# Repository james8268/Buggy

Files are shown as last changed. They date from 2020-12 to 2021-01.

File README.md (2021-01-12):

# Read Me file for understanding how to use the Buggy.

## Functionality of the Buggy. 
The Buggy has 3 main forms of interaction; a remote mode where the buggy can be controlled by the user through Bluetooth/WiFi/IR commands, an autonomous mode where the buggy is commanded by the user to roam freely without colliding into obstacles and a measuring mode where the buggy will move around autonomously but will take temperature and water level reading when it stops due to an obstacle. 

There are 4 methods of controlling the buggy:
* IR Remote
* Bluetooth LE
* WiFi
* Direclty through the PC serial monitor. 

## Getting started. 
When using any method of control, when then buggy is powered up it will request the user to present the correct RFID tag/card to the scanner. If the user does not present the correct RFID tag/card then access to the buggy will be denied. In order to be able to use the buggy the RFID tag/card must be presented. 





Once access is granted the user can then control the buggy by any of the control methods. 

## How to use the IR Remote. 
The IR remote is the most simple way of interacting with the buggy. This method does not use the ESP32 so this can be disconnected via the RX and TX pins.



The function each button has is as follows:  
* 1 - Move the buggy farwards slowly.
* 2 - Move the buggy forwards 
* 3 or up arrow - Move the buggy forwards at maximum speed. 
* down arrow - Reverse the buggy
* ok - Stop the buggy
* Left arrow - Rotates the buggy left
* Right arrow - rotates the buggy right
* \* - take a temperature reading and display it on the LCD screen
* \# - Stops the buggy before taking a water level reading. 

## How to control the buggy using Bluetooth low energy (BLE).
When the Bluetooth.ino code has been uploaded to the ESP32 you can connect an android device only (IOS does not support BLE).
By going into the android device settings, "ESP32test" will be able to be paired with the device. 



Then using the below Serial Bluetooth terminal, the ESP32 can be set up as a device and connected to the ESP32.




As you can see in the bluetooth terminal there are hot keys provided. Like the IR remote the number "3" will move the buggy at full speed and the hotkey "stop" will stop the buggy. 



To allow the buggy to roam autonomously and roam autonomously while taking temperature, humidity and water level measurements, "E" and "M" can be sent to the terminal respectively. To stop the buggy roaming autonomously just press the "stop" hotkey.




As you can see the buggy will do an initial assessment of its surroundings and checks the distance in front of it (Cdist), to the left of it (Ldist) and to the right of it (Rdist). It will then choose which is greatest and move in that direction. It will then stream the distance it has until its next obstacle. When the distance is under 30cm it will stop and reasses it's surroundings to find the greatest clearance. 

You can also request a temperature/humidity or water level reading in the remote control setup by sending "T" and "W" respectively. 

## Using WiFi to controll the buggy. 
The ESP32 needs to be programmed in either the Blynk method which is highly customizable or by using a standard WiFi connection which controls the buggy using a WiFi terminal. (These are IOS friendly). You must upload either the BLYNK_WiFi.ino or standard_wifi.ino to the ESP32 to communicate with the buggy via WiFi. 
### BLYNK_WiFi
Blynk is a app which is extremely user friendly! It is highly customizable as you can add joy stick, buttons, sliders and much more. 
When the ESP32 is connecting/connected to your network and to the Blynk server it will display a message when connected to the serial port.




In the Blynk App we can insert a terminal which allows us to control the buggy. Unlike the the bluetooth terminal this does not have hotkeys which means you need to know the directory for how to control the buggy. Which is as follows:
* 3 -Will move the buggy forwards at full speed.
* 2 -will move the buggy forwards
* 1 -will move the buggy forwards slowly
* h -will stop the buggy (Halt)
* b -will reverse the buggy
* l -will rotate the buggy left approximately 50 degrees
* r -will rotate the buggy right approximately 50 degrees
* E -will allow the buggy to roam freely while avoiding ibstacles
* M -will allow the buggy to roam freely will avoiding obstacles and taking temperature, humidity and water level measurements. 
* T -will measure and instant temperature reading
* W -will stop the buggy moving if it is moving and will take a water sensor reading. 

As you can see below it is similar to the bluetooth terminal, just without the hotkeys. 





### Standard (Standard_WiFi)
The standard method of using WiFi is very similar but requires a few more steps. 
When the ESP32 Connects to the network and server a message will be displayed in the serial monitor.




Using the WiFi serial app, input your IP address displayed in the serial monitor along with the port number which is set to 80. 



This will then connect you to the ESP32 network and allow you to control the buggy. The top window is when your input commands for the buggy and the bottom window is the feedback which is sent to you. Be warned this specific app has no auto scroll function, so as soon as the feedback window is full you need to clear it by pressing the bin at the bottom. 





## Using the Serial monitor to control the buggy.
This method has limitations, for example the buggy must stay plugged into the laptop/PC so limites mobility. However an ESP32 device is not required so there are no connection issues. This method is very useful for running quick tests to see how the buggy operates without having to leave your chair, you can just prop the buggy up to remove contact between the wheels and the floor. 
This method is similar to the IR remote in a sense that the ESP32 is not needed so the RX and TX pins can be disconnected. 
Some functions are limited also, Roaming autonomously is not recomended as the board has to be manually reset with the reset button on the arduino board. 

You can see below when commands are sent through the command line in the serial monitor window you will still recieve the feedback from the buggy. 

BR

brr

brrr

wt

## Security features
 
Some security features have been added:
* RFID - The buggy requires a correct RFID tag to be presented before anything initially takes place and is also required when any form of autonomous mode is exited, this makes sure the user has visual confirmation of the buggy's loaction. 
* A tilt sensor- If the buggy tips over a tilt sensor will be activated. This will halt the buggy and sound a buzzer. This is activated when the buggy is in a remote or autonomous mode. A message will also be sent to the Bluetooth/WiFi terminal to notify the user.
* Red LED- if connection between Bluetooth/WiFi drops then the Red LED located on the front of the buggy will turn on, the buggy will stop and anything written on the LCD screen is cleared.

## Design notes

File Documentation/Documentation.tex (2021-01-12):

\documentclass[8pt, a4paper]{article}
\usepackage{geometry}
\geometry{total={170mm, 257mm},left=20mm, top=20mm}
\usepackage{graphicx}
\usepackage{float}
\usepackage{hyperref}
\usepackage{listings}

\begin{document}
\setlength \topmargin{-1in}
\title{\textbf{Software Engineering for Distributed and Interactive Systems.}}
\author{\textbf{James Ravenhill}}
\date{}
\maketitle

\section{Introduction} 

The main outcome at the beginning of the project was to create a simple and easy to used piece of software which allows the user to control the buggy without being too complex. Both the hardware and software have been an ongoing development based on feedback given through multiple tests, which a few friends generously took part in. The main objectives of the project are listed below but not limited to:

\begin{itemize}
	\item Reliability - Unreliable connection/data transfer is a disadvantage and creates more problems. This will be explained later in more detail.  
	\item  Multiple methods of communication - By using WiFi, Bluetooth, IR remote and a PC. 
	\item Scalability - There should be no software problems while developing the increased load of sensor/capabilities of the buggy. 
	\item Maintainability - comments/documentation should be clear to allow future developers to understand the project decisions as they happen. 
	\item Autonomous - The buggy must have the ability to move in and out of an autonomous mode.  
\end{itemize}

In this document short snips of the main code will be used in explanations. The main raw code can be found in the submitted documents or on my $\href{https://github.com/james8268/Buggy}{Github}$ account. The demonstration video can be found using this \href{https://web.microsoftstream.com/video/7f82516f-c8d7-4af7-9546-ee9eb85d3bd6}{stream} link or you can copy and paste this \verb|https://web.microsoftstream.com/video/7f82516f-c8d7-4af7-9546-ee9eb85d3bd6|.

\section{Design}
In terms of hardware design, the overall aesthetic is not very relevant. This being said, proper cable management and reducing the risk of damaging hardware was a great challenge due to the limited mounting points on the buggy. This challenge was overcome by using blue tac or Velcro to attach the hardware to the buggy without damaging the hardware in the process. 

\begin{figure}[H]
\centering
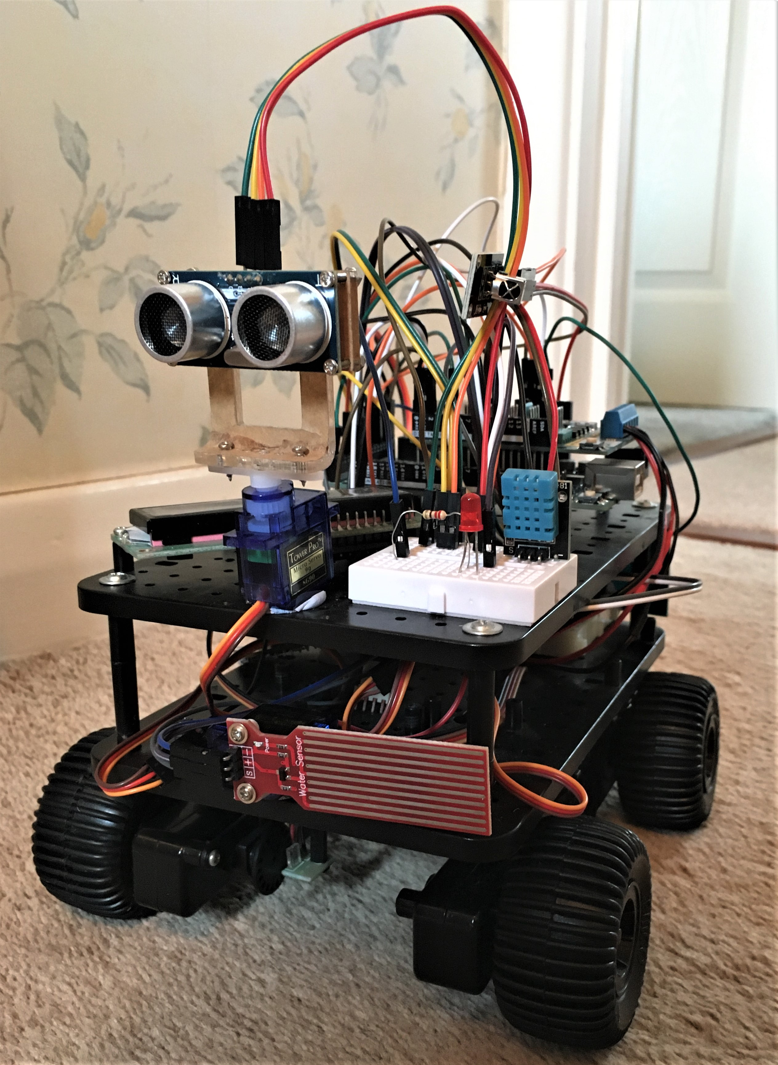
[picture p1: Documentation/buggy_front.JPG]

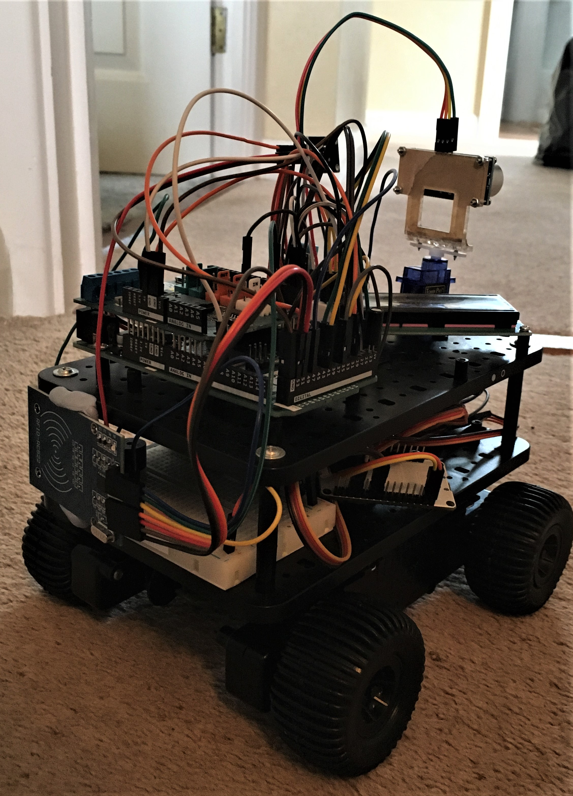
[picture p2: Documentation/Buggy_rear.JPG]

\caption{Left: Image of Buggy from the front left corner.}
\caption{Right: Image of Buggy from rear right corner.}
\end{figure} 

Below are two images of the main schematic of the buggy and a general communications diagram. 

\begin{figure}[H]
	\centering
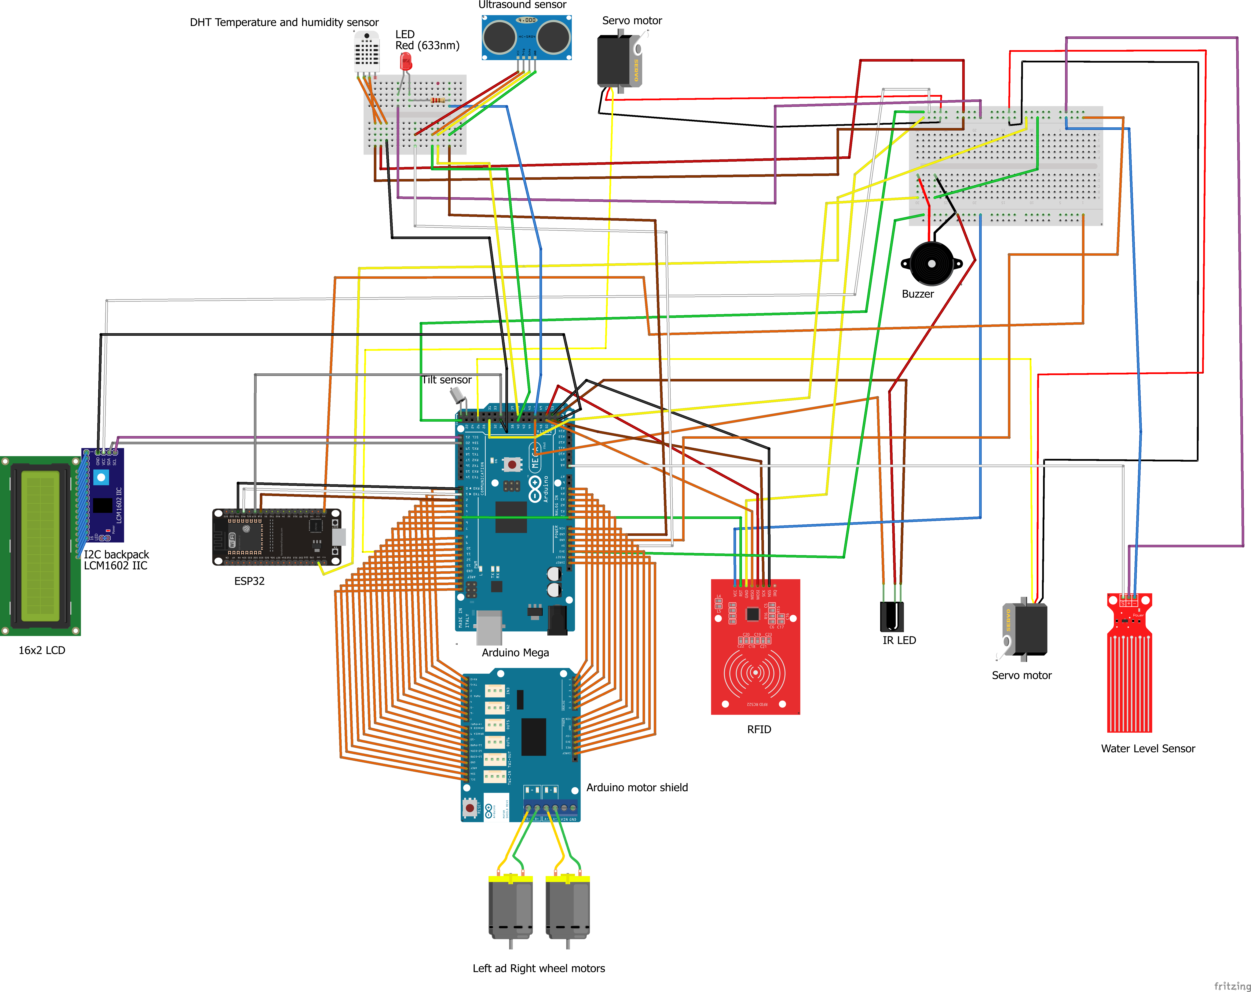
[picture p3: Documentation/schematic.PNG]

\caption{Schematic of Buggy.}
\end{figure}

\begin{figure}[H]
	\centering
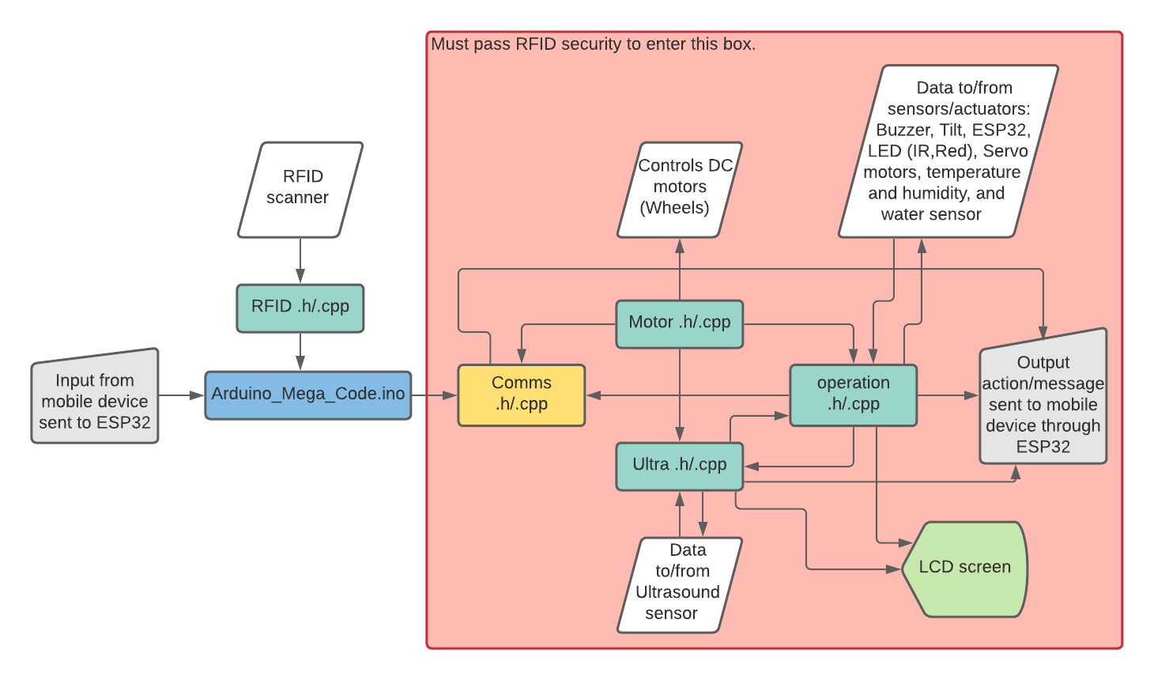
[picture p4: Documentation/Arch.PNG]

\caption{Communication diagram of the Buggy}
\end{figure}

The software for the Arduino has been set up into header (.h) files and source code (.cpp) files where they are then called in the main code. There are many benefits to this such as the code is organised and tidy. This allows future and current developers to debug with ease and addition of any new code can be easily integrated into the system while the code can be easily maintained. 

\begin{figure}[H]
	
	\caption{Tabs for Arduino mega main code.}
\end{figure}

In Figure 4 you can see how the system communicates between source files. The main system that operates the buggy can not be accessed without first passing the RFID security tag challenge. Further development to encrypt data that is sent between the mobile device and ESP32 needs to be done, a attempt to create a rotation 13 encryption has been attempted but needs to be placed correctly within the architecture of the system for it to work. 

The Buggy can be controlled with various methods.
\begin{itemize}
	\item Bluetooth- The buggy can be controlled with a mobile device via Bluetooth. With this method the buggy can be used to its full potential and all functions are available, this includes influencing the direction of the buggy, taking measurements and allowing the buggy to move around autonomously while avoiding obstacles. 
	\item WiFi- The buggy can also be controlled with a mobile device via WiFi. This method also allows the user to use the buggy to its full potential. 
	\item IR Remote- This works well when in close proximity to the buggy or when simultaneously using a mobile device to control the buggy. The limitation to this is that you can not control the buggy for its autonomous mode when using the IR remote.
	\item PC- The serial monitor can also be used to control the buggy, but like the IR remote the buggy can not be controlled autonomously with this method. 
	\item WiFi and Bluetooth- The ESP32 has a dual core CPU so Bluetooth and WiFi can be used on two separate mobile devices to control the buggy simultaneously.  
\end{itemize}	

\section{Implementation}

The software for the ESP32 comprised of individual source code files which correspond to the use of WiFi or Bluetooth and for both due to the ESP32 being dual-core. Transmission control protocol (TCP) has been used when using WiFi instead of user diagram protocol (UDP) as is it more reliable, has flow control so will not overwhelm the receiver and has congestion control. A 'handshake' is used to initiate communication and then multiple packets are sent. TCP may not be as fast as UDP but due to the project objectives, reliability is preferred. This being said TCP is slower by a very small margin so is not a large hindrance on the usability of the system. 

A distributed system is a system which coordinates is actions by communicating between components via passing messages. The example for this project are listed and explained below.

\begin{itemize}
	\item Mobile device-ESP32-Arduino maga: The mobile device communicated to the ESP32 through WiFi (TCP) or Bluetooth, the message that is received by the ESP32 in then passed onto the Arduino mega by universal asynchronous receiver/transmitter (UART). UART is not a communication protocol but is rather a physical circuit where serial data is transmitted and received. This emphasises the reliability factor as no data will be lost over the wired connection. When the Arduino receives a message/command the source code will then action this. If a feedback message is needed it will be sent back to the Mobile device. This will happen in a reverse process, the data will be sent to the ESP32 via UART and then be sent to the mobile device by WiFi/Bluetooth. 
	\item IR signal-Arduino: The IR LED input signal was initially received in the mini-bread board but this caused problems while testing due to high volumes of ambient noise, it was therefore moved directly onto the Arduino mega. This therefore means that the IR remote can by used at the same time as the mobile device. The LCD uses the I2C bus to print messages on the screen when temperature, humidity and water sensor readings are requested. 
	\item  PC-Arduino: When the PC is connected directly to the Arduino mega and is controlled using the serial monitor it is very useful for conducting quick simple tests, if new code is added to the software for example. 
	\item ESP32 disconnection feature: When the ESP32 disconnects from the WiFi router or Bluetooth then a signal will be sent to the Arduino mega. When this signal is received the buggy will stop, the LCD screen will be cleared and a red LED will light up to alert the user. 
\end{itemize} 

The interactivity between the buggy and the user (besides the obvious mobile device (WiFi/Bluetooth), PC communication and IR remote) consist of the following lower levels of interactiveness:

\begin{itemize}
	\item RFID scanner- This provides security as the RFID tag/card must be presented before any use of the buggy can take place. 
	\item Tilt sensor- This sends a message to the mobile device/PC as well as sounding an alarm to communicate to the user that the buggy has tipped over due to complex/uneven terrain. 
	\item Disconnection LED- The red LED on the front of the buggy lights up when the WiFi/Bluetooth connection drops, if the buggy is moving around and a disconnection occurs the buggy is programmed to stop automatically.   
	\item Ultrasound sensor- This interacts with its surroundings to gain distance information. This information can then be actioned accordingly, for example while in an autonomous mode distance information will be used to make decisions on which direction to turn and to avoid obstacles. 
	\item Temperature, humidity and water level sensor- All of these sensors are controlled by the user. A safety feature also exist if the buggy is moving and a water sensor reading is requested the buggy will first stop and then take the reading, this will reduce the risk of damaging the water sensor. 
\end{itemize}

These may seem like simple solutions to certain problems but they are efficient and prove effective during testing. They also provide a level of security to the buggy, for example if a new RFID tag is to be added it can only be done so by adding it to the source code.  

When commands have been received from the mobile device by the ESP32, the ESP32 will receive this message and send it to the Arduino via UART as mentioned above. Any messages sent from the Arduino are communicated back in the same way. 
 
\begin{figure}[H]
	\centering
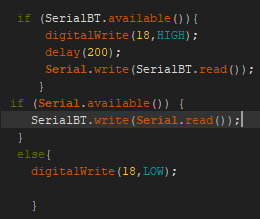
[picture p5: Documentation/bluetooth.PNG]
	
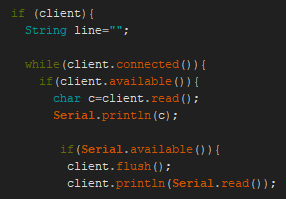
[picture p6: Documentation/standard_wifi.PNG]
	
	\caption{Left: ESP32 Bluetooth main loop code.}
	\caption{Right: ESP32 standard Wifi main loop code.}
\end{figure}

Blynk is a library that when connected to its app on any mobile device provides a very aesthetic design for the user, it is also very customizable for varying project requirements.
The way it has been used in my case is of a similar procedure but is not as straightforward as the Bluetooth or standard WiFi set up. As you can see below, two functions are created with \verb|'BLYNK_WRITE'| being a Blynk library that reads commands from the mobile device and sends them to the Arduino and \verb|'SerialInput'| being the function which sends messages from the Arduino to the mobile device.

\begin{figure}[H]
	\centering
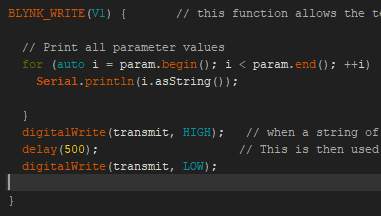
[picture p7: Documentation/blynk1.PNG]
	
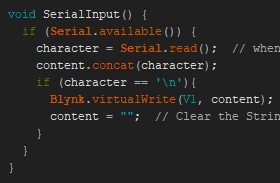
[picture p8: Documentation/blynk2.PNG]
	
	\caption{Left: ESP32 Blynk read from the mobile device and send messages to the Arduino Mega.}
	\caption{Right: ESP32 Blynk read meaasges from arduino and send to mobile device}
\end{figure}

The ESP32 is a Dual core micro-controller and in theory can be used for a combined Bluetooth and WiFi mode. As you can see from the figure below this was attempted and does work, however there is one issue. Because the procedure for sending messages back to the mobile devices are virtually the same for WiFi and Bluetooth, the ESP32 has no distinction between which device it has received a command from and therefore which device to send messages back to.

\begin{figure}[H]
	\centering
	
	\caption{Setup for ESP32 dual core WiFi and Bluetooth.}
\end{figure}

Looking at the figure below you can see the main loop for the Arduino mega. The commands here are reading the serial monitor when the buggy is connected to the PC as well as the IR remote control reader and the ESP32 reader (this reads messages from the mobile device). Other commands that monitor the tilt sensor and the Wifi/Bluetooth connection are at the bottom of Figure 11. 

\begin{figure}[H]
\centering
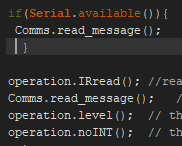
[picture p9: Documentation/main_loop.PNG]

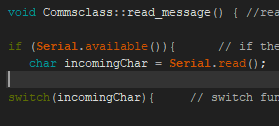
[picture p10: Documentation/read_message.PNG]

\caption{Left: Arduino mega main loop}
\caption{Right: Read incoming message}
\end{figure}

When a command is actioned by the Arduino Mega it will enter a \verb|switch| loop, here is where commands are executed. Each command corresponds to a function which exist in other source code files.

\begin{figure}[H]
	\centering
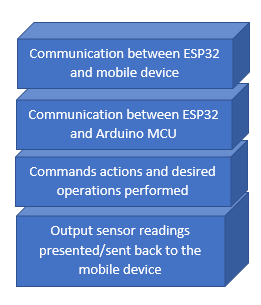
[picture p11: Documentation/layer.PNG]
	
	\caption{Layer diagram of the Buggies distributed system.}

\end{figure}

This layered system allows for easy maintenance and the system can be easily updated/developed. The first layer of the system is the communication to and from the ESP32 and the mobile device. This will consist of commands for a desired operation/function or a message sent to the mobile device. The second layer is where the data is then communicated between the ESP32 to the Arduino mega. The ESP32 acts as a relay for communication. When the IR remote is in use the first two layers are not present and the IR LED communicates directly to the Arduino mega. The final two layers are responsible for performing the desired operation or function depending on what command has been given, the results are then communicated back to the user on the mobile device or on the LCD screen.  

\section{Testing}

The variety of testing methods used from start to finish have varied from unit and integration testing to acceptance and regression testing. The unit testing has taken place when a new operation/function has been added to the source code and is performed by myself for verification. The integration tests have then been performed by others to make sure that the new function works within the rest of the system and performs how it is expected to perform (acceptance testing). As the project has developed regression testing has been used to verify that any changes have not affected the prior system. Tests with comments can be found in the appendices.

One of the first problems discovered was with the ultrasound sensor (USS), in complex environments the USS would not recognise the correct distance and the buggy would therefore collide with obstacles. Complex environments such as chair legs and/or approaching a wall at a 45$^{\circ}$ angle. The reason for the USS difficulty in getting the correct distances is due to its transmitter-receiver architecture, if either one is blocked then the correct distance cannot be obtained and the buggy collides with the obstacle. For this reason, to reduce any damage to the hardware a tilt sensor was added. This feature when triggered will stop any movement of the buggy and will send a warning signal to the mobile device terminal. Initially the USS was fixed and when an obstacle was detected the buggy was set to turn left as a default. Since placing the USS on a servo motor it has become better at sensing obstacles and making decisions on which direction is best to move in before colliding with an obstacle. 

\begin{figure}[H]
	\centering
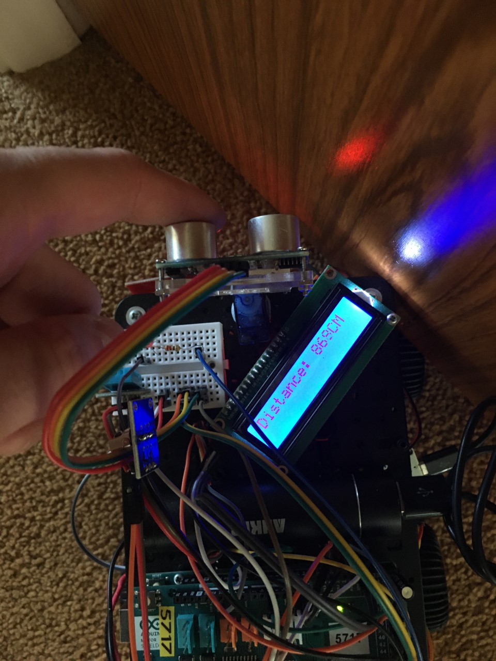
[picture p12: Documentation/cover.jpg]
	
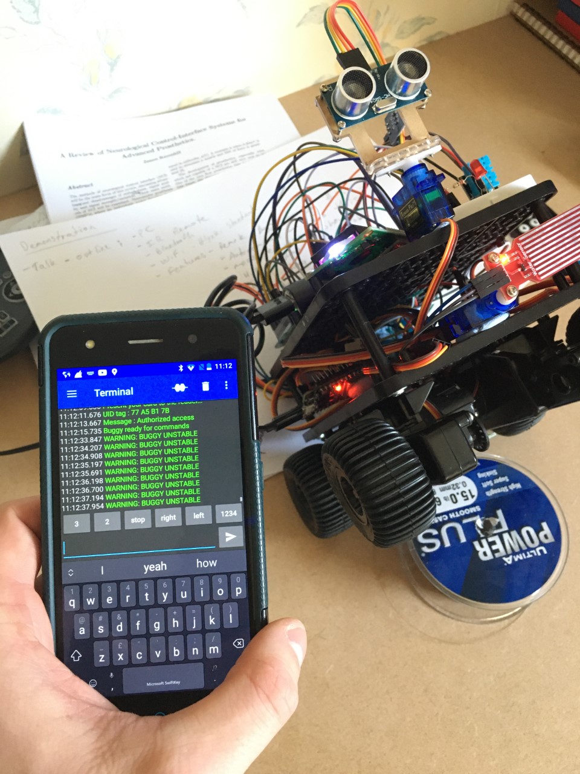
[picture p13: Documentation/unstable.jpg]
	
	\caption{Left: Covering receiver/transmitter on approach to an obstacle and the USS showing a incorrect distance of 869CM.}
	\caption{Right: Unstable message displayed when buggy is tilted.}
\end{figure}

When the decision to add a IR remote which is able to control the buggy was made, initially there were issues. Noise from ambient light, other IR sources and even electrical signals within the breadboard caused overflow issues. Any command received from the IR remote would not be read and processed. 

What I found was happening is that any electrical signal to or from the ultrasound sensor was being spread throughout the pin ports in the breadboard (This is due to it being a small cheap breadboard) and this interfered with the IR LED electrical signal. To over come this the signal pin for the IR LED was relocated to the main Arduino mega board, This reduced the noise considerably.  

Any loss of communication is a important problem that must be resolved. To combat this the ESP32 monitors WiFi/Bluetooth connection and if any connection is lost the ESP32 sends a signal to the Arduino Mega. This signal will stop the buggy and turn the front red LED light on. No message is sent to the mobile device as there is no connection so it would be pointless. When the connection is lost the LCD is also cleared. The ESP32 will attempt to restart the setup instructions to regain connection. 

\begin{figure}[H]
	\centering
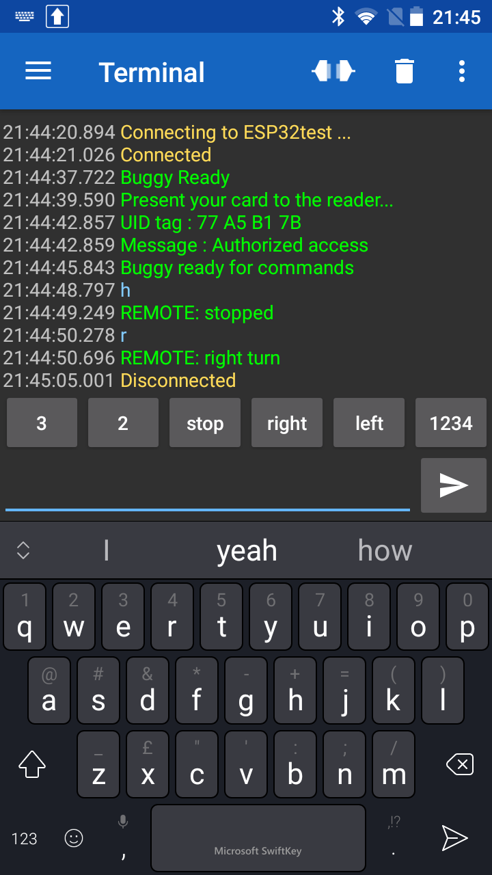
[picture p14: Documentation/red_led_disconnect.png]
	
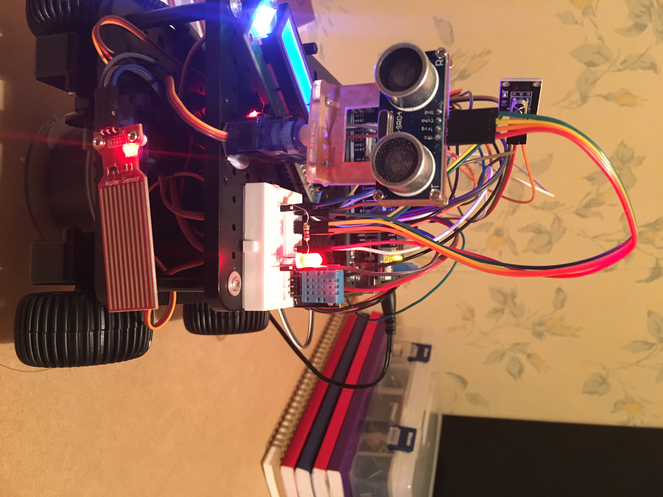
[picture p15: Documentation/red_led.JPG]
	
	\caption{Left: Mobile device connecting and then disconnecting from the buggy.}
	\caption{Red LED on, after mobile device disconnects from buggy.}
\end{figure} 

Some basic tests on the accuracy of the ultrasound and water sensor were also conducted. When testing the accuracy of the ultrasound sensor a ruler was placed at the base of the sensor and a book was moved closer in intervals of 5cm starting from 5cm to 90cm. The recorded result was then noted and compared against the actual result. 

\begin{figure}[H]
	\centering
	\begin{tabular}{|c|c|c|}
		\hline
		Measured distance (cm) & Recorded distance (cm) & \verb|%| Error\\
		\hline
		 5 & 3 & 40 \\   
		 10 & 7 & 30\\
		 15 & 10 & 33 \\
		 20 & 14 & 30\\
		 25 & 17 & 32\\
		 30 & 21 & 30\\
		 35 & 23 & 34\\
		 40 & 27 & 33\\
		 45 & 30 & 33\\
		 50 & 34 & 32\\
		 55 & 37 & 33\\
		 60 & 41 & 32\\
		 65 & 44 & 32\\
 		 70 & 47 & 33\\
		 75 & 51 & 32\\
		 80 & 54 & 33\\
		 85 & 58 & 32\\
		 90 & 53 & 30\\
		\hline
	\end{tabular}
	\caption{Table of figures for ultrasound sensor test.}
\end{figure}

The \verb|%| error is relatively constant throughout which in our case isn't a bad thing, as it will allow me to calibrate the distance output by applying an offset of approximately 30 \verb|%|. This being said the ultrasound sensor still provides the buggy with efficient feedback of the distance from obstacles so no calibration will take place. Calibration will just remain an option if needed in the future.  

The water sensor was slightly different when it came to testing. The software is setup to provide a ranged output for the sensor reading (Empty, low, medium and High). These ranges can be calibrated in the source code, but I still tested the sensor to see how the difference in water levels affected the output. The sensor was split up into intervals and water is applied in cumulative segments. The output is then recorded, the output can be recalibrated depending on how sensitive the user wants the sensor to be. 

\begin{figure}[H]
	\centering
	\begin{tabular}{|c|c|}
		\hline
		Depth submerged (cm) & Recorded output\\
		\hline
        0.0 & Empty\\
        0.5 & Low\\
        1.0 & Low\\
        1.5 & Medium\\
        2.0 & Medium\\
        2.5 & Medium\\
        3.0 & High\\
        3.5 & High\\
        4.0 & High\\
		\hline
	\end{tabular}
	\caption{Table of figures for water sensor test.}
\end{figure}
From the water sensor figures in the table above we can see that the water sensor is well calibrated for the situation of the buggy. As mentioned before the sensitivity of the water sensor can be changed in the source code by changing the analogue ranges for each corresponding level of empty, low, medium and high. 

\section{Evaluation}

There are some limitations to each method of distribution. When comparing the WiFi and Bluetooth methods when using the mobile device the Bluetooth is more favourable. This has been fed-back from testing as well as personal experience. The WiFi and Bluetooth methods allow you to use the buggy to its full potential, however when it comes to usability the Bluetooth shines through. The reasons for this is that Bluetooth can be used anywhere and does not depend on a network connection like WiFi. The disconnection function is also instant when it come to using Bluetooth whereas there is a 10 second delay time for the buggy to realise it has disconnected from the local network when using the WiFi. 

Using the IR remote and PC are quite similar, they are both slightly limited as can not be used to stop the buggy from roaming around autonomously. This is due to the architecture of the source code. The buggy exits the autonomous mode when the ESP32 communicates to the Arduino, obviously because we are not using the ESP32 while using the IR remote or PC serial monitor then there is no way of signalling the Arduino to stop the buggy moving around autonomously. An attempt however was made so the IR remote would be able to signal the Arduino to exit its autonomous mode when a signal is received by the IR LED. Unfortunately because there is still some IR noise that exists in the external environment the buggy stops roaming around autonomously when no such command is given. 

The combination of using the IR remote and a mobile device is a great feature. When you are using the mobile device, you can control to buggy from a different room if you wanted to, whereas the user is unable to do this with the IR remote. The IR remote can however be used simultaneously with a mobile device, so two people can control the buggy at the same time. This is useful as if there is a connection issue with the IR remote then the buggy can still be controlled with the mobile device or visa versa. 

When using the buggy in a Bluetooth mode, two devices can not be connected to the buggy. However when using the dual-core capability of the ESP32 (with one core setup using WiFi and the other Bluetooth) two mobile devices can be connected. This works well however, any messages sent back to the mobile devices from the buggy can get scrambled. This means that if the first mobile device sends a command to the buggy, the returning message will be delivered to the other device. There are positives and negatives for this. One positive is that it allows the other user to know what is happening with the buggy but the one that issues the command does not know if the command has been executed other than by physically watching the buggy. 

As you can see below when a command is sent from the Bluetooth terminal any messages responding to this command come back through the WiFi terminal and visa versa. 
	
	\begin{figure}[H]
		\centering
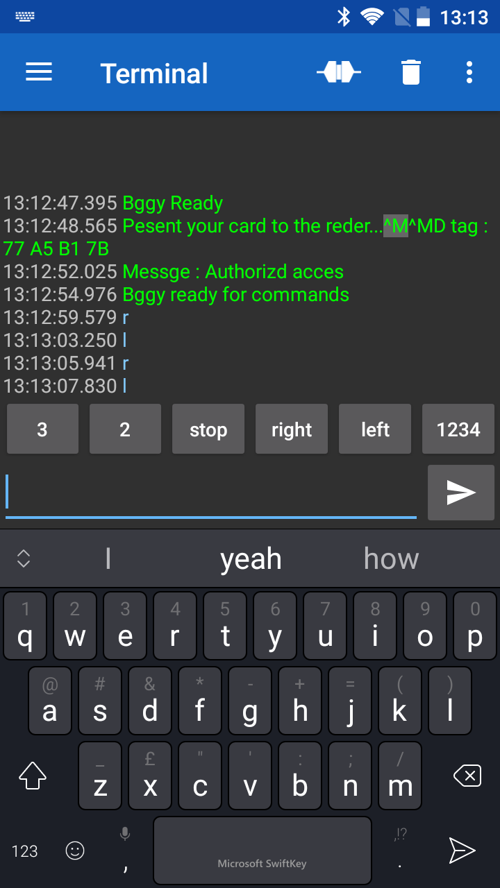
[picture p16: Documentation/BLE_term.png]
		
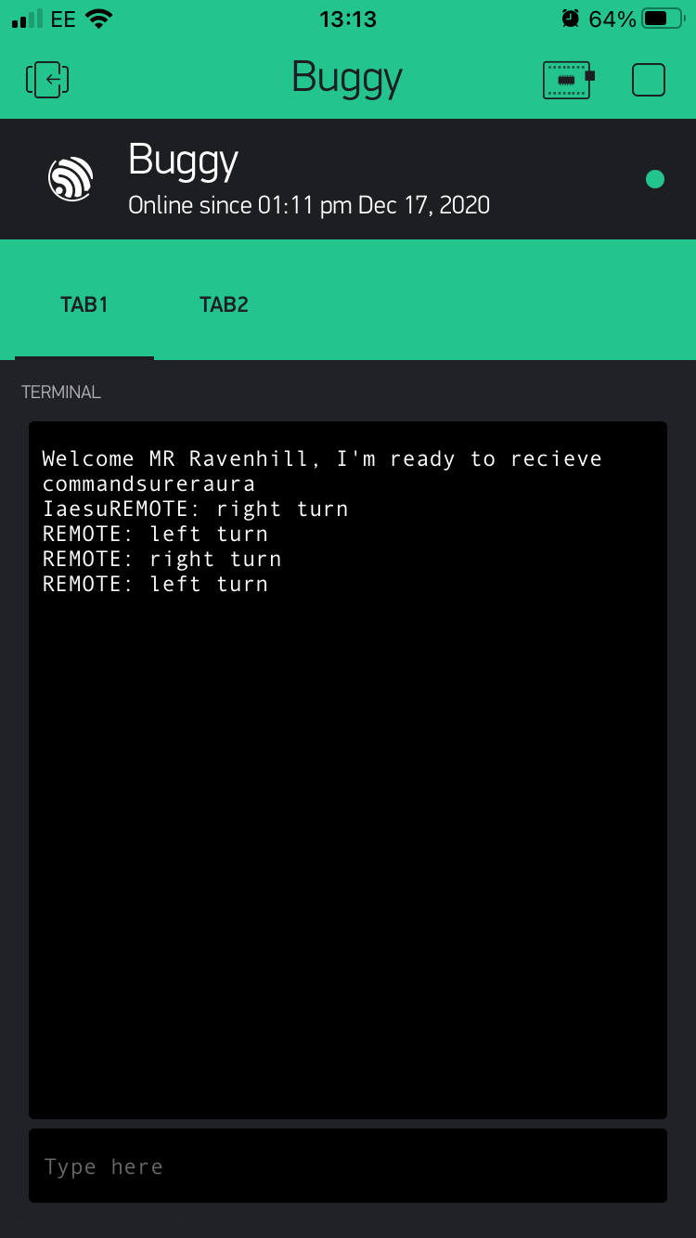
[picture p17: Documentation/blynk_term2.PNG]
		
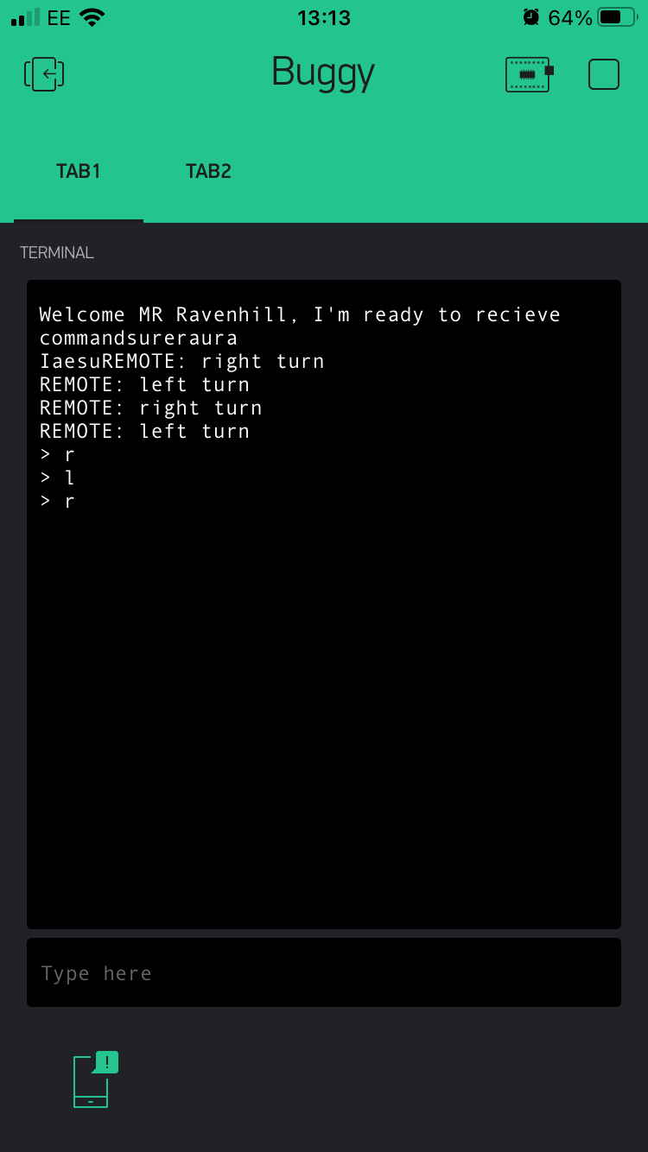
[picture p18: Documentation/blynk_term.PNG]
		
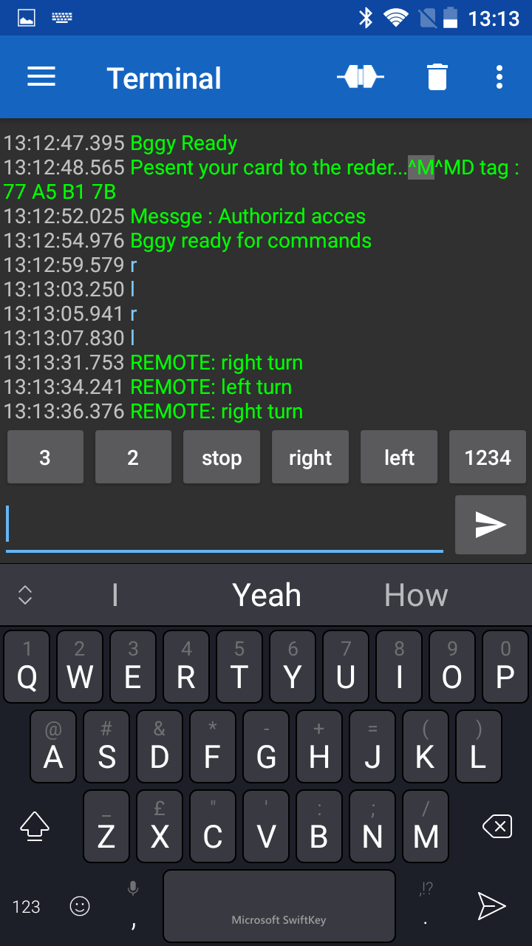
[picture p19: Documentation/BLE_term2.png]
		
		\caption{From Left to Right: Bluetooth terminal giving commands. WiFi terminal receiving messages. WiFi terminal sending commands. Bluetooth terminal receiving messages.}			
	\end{figure}

\section{Code remarks}

The ReadMe file can be found in the \href{https://github.com/james8268/Buggy}{Github repository} or along with the submitted documents. 

\section{Conclusion}
To summarise the key aims of the project were to create a buggy with reliable software which can be controlled with multiple methods while being scalable, maintainable and have a autonomous element. I believe that all of the set aims have been met. The buggy has been developed and redesigned due to feedback from multiple tests. Some challenges were faced along the way and future development should take place in making the buggy more secure, for example finishing the encryption of data sent between the ESP32 and the mobile device. Future work on making the ultrasound sensor more accurate and responsive (to reduce collisions with complex obstacles). This could be achieved simply by adding multiple ultrasound sensors which work together in a distributed system or by substituting the ultrasound sensor for a light detection and ranging module (LIDAR). 

\newpage
\section{Reference Library and appendices}
\subsection{Github account}

\href{https://github.com/james8268/Buggy}{Click here for Github hyper link} 

or copy and paste the URL into your web browser. https://github.com/james8268/Buggy

\listoffigures

\subsection{Third party libraries}

\verb|arduino.h|, \verb|LiquidCrystal_I2C.h|, \verb|IRremote.h|, \verb|Wire.h|, \verb|dht.h|, \verb|SPI.h|, \verb|MFRC522.h|, \verb|WiFi.h|, \verb|WiFiClient.h|, \verb|BlynkSimpleEsp32.h|, \verb|Servo.h| and \verb|BluetoothSerial.h|

\subsection{Test Comments}
\begin{itemize}

\item Test 1,Getting to grips with the Bluetooth, 28/10/2020: The device worked exactly how it should every command button worked as it should. The controls were very easy to understand and get to grips with which means I could use the buggy how I wanted with no issues. Only thing I would like to add is that the left and right turns be a little less aggressive. So instead of a 90 degree turn maybe a 45 instead. Also I would like the distance of the sensor to be displayed on the mobile device as well as the LCD screen on the buggy so I don’t have to be stood directly over the buggy to know this information, as I think this would make it more user friendly. Other than that, it was flawless.

\item Test 2, This test is like the last with a few minor changes. This time around the buggy is in a combined remote Bluetooth and autonomous mode. The autonomous element will allow the buggy to roam freely while avoiding obstacles.

Acting on the previous test a feature of being able to see the reading of the ultrasound sensor has now been added and can be viewed in the mobile device terminal as well as the turns being less harsh.

\item Test 2.1, using the combined autonomous and Bluetooth mode, 04/11/2020: self-roaming was effective, the buggy avoided obstacles well, although had trouble once it was under a certain distance from complex obstacles. commands were easy to pick up and the buggy was easy to manoeuvre, although lag time could be reduced, or possibly a cut off after x number of commands. possibly introduce a short cut to speed one and/or options for varying stop times, so that when flustered a driver can take time to re-think.

\item Test 2.2, test is the same as previous (code remains the same as the last test), 05/11/2020: the buggy avoided the obstacles well however due to lag it made it difficult to manoeuvre, also would be much easier and efficient for the driver if there was a cut off command so that the user can re-access the situation and move from there.  

\item Test 3, The buggy now can roam around autonomously while avoiding obstacles and this can then be stopped and be used remotely again. It’s easy to switch between the two, using the mobile device terminal the "roam" hotkey enters the buggy into an autonomous mode(which can be seen when the android device is tilted on a landscape view and the screen will show more potential hotkeys). when any button/command is used in the terminal the buggy will then exit the autonomous mode and reverts to a remote mode. 

Test 3, testing combined autonomous and remote modes, 07/11/2020: I enjoyed the new features on the handset. The fact that the buggy now had a roam feature was very interesting. The fact it could now make decisions on what was in front of it and change the course on which it was travelling due to an object being in its way was fascinating. A cool feature would be if it could decide which way it wanted to turn. For instance, left or right depending on the amount of space it has either side, this depends on the amount ultrasound sensors it has available. All the other buttons worked well and did what I wanted when I asked it to. 

\item Test 4, A tilt sensor and servo motor have now been added, the use of WIFI connection is also up and running. Security measures have been added so if WIFI or Bluetooth connection is lost it will stop the buggy and turn on the front red LED. The servo motor allows the buggy to look left and right and then decide on which direction to move. The tilt sensor will monitor the buggy and if it capsizes or is flipped over it will stop the buggy and turn on a buzzer as well as notifying the user if in remote mode. 

tests to be completed:
\begin{itemize}
\item turning system for servo ultrasound sensor, just to check its working right.
\item tilt sensor while in autonomous mode while moving. 
\item temp and humidity sensor and water sensor while moving and stationary. 
\item disconnect functions via Bluetooth, by trying to connect another device (already known that two devices can’t connect over Bluetooth).
\item disconnect from WiFi, turn off router. 
\item test overall usability.
\end{itemize}

\item Test 4, 23/11/2020, testing the new obstacle avoidance system, tilt sensor and the temp, humidity and water sensor (all in Bluetooth mode): I found the new obstacle avoidance system was very good the Buggy made very accurate adjustments when it came to an obstruction. the fact it was able to stop look around and decide for itself which way to go was very impressive. the tilt sensor that has been integrated into the buggy was a very impressive feature. especially since you had the use of this both in autonomous mode and just when controlling the buggy, yourself. also having the bonus of a water, temp and humidity sensor on it was very good. being able to see those readings was a nice feature to have the use of. I also found the use of the IR remote to be far more simplistic and easier to use than the Bluetooth device I much preferred it. there was a few points I feel could do with some improvement. for instance, when you are on the move and then ask the buggy to perform a water reading it stops does this command but then waits for another new instructions. I would like it to instantly carry on with the previous command once the reading has been carried out with no need to give it further instruction from either the Bluetooth device or IR remote. other than that, the buggy was very good.

\item Test 5,A RFID security tag has been added for security. 
Test 5, first time using WIFI set up and looking at disconnection issues. To then compare the WIFI and Bluetooth usability, 11/12/20: 

Using BLYNK: was detailed and easy to use. Very easy to read the screen. All commands worked straight away. Liked the safety feature as well the fact you had to use a key fob to be able to use the buggy. Also, the fact it tells you on the buggy with a red led that it is disconnected from the internet and you no longer have control of the buggy. 

Standard WIFI:  wasn’t as easy to use. Didn’t like the fact every time you placed a command the keyboard went away so you had to click on the box again to load a command. When I asked for a temp reading it wasn’t displayed on the WIFI app. Just gave me a random number. Also, when disconnected from the internet the red led light didn’t show on the buggy to indicate it was inoperable, however it did show on the WIFI app that it had been disconnected from the network.  

Comparison to Bluetooth: WIFI was good but the Bluetooth was far better in my opinion as I can used the buggy anywhere at any time I like with ease. Whereas with the WIFI you must have that connected to be able to use the buggy. Also, the Bluetooth has the hot keys which made the whole experience of using the buggy more user friendly and easier. 

\item Test 6, re-testing Standard WiFi, 09/01/2020: the WiFi app was much easier to use this time. would be good if there were hot keys like on the Bluetooth app for ease of use. also it was much better that it now gave an accurate temp, humidity and water reading on the screen not just a bunch of random numbers like before. I also see that the led light to indicate disconnection from the network worked now as well. Not just the information being displayed on the WiFi app that it had disconnected from the network but the LED working as well.

\end{itemize} 

\end{document}

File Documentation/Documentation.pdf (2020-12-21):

# Software Engineering for Distributed and Interactive

Systems.

James Ravenhill

## 1 Introduction

The main outcome at the beginning of the project was to create a simple and easy to used piece of software which allows the user to control the buggy without being too complex. Both the hardware and software have been an ongoing development based on feedback given through multiple tests, which a few friends generously took part in. The main objectives of the project are listed below but not limited to:

- Reliability - Unreliable connection/data transfer is a disadvantage and creates more problems. This will be explained later in more detail.
- Multiple methods of communication - By using WiFi, Bluetooth, IR remote and PC.
- Scalability - There should be no software problems while developing the increased load of sensor/capabil-ities of the buggy.
- Maintainability - comments/documentation is clear to allow future developers to understand the project decisions as they happen.
- Autonomous - The buggy has the ability to move in and out of an autonomous mode.

In this document short snips of the main code will be used in explanations. The main raw code can be found in the submitted documents or on my Github (https://github.com/james8268/Buggy) account.

## 2 Design

In terms of hardware design, the overall aesthetic is not very relevant. This being said, proper cable management and reducing the risk of damaging hardware was a great challenge due to the limited mounting points on the buggy. This challenge was overcome by using blue tac or Velcro to attach the hardware to the buggy without damaging the hardware in the process.

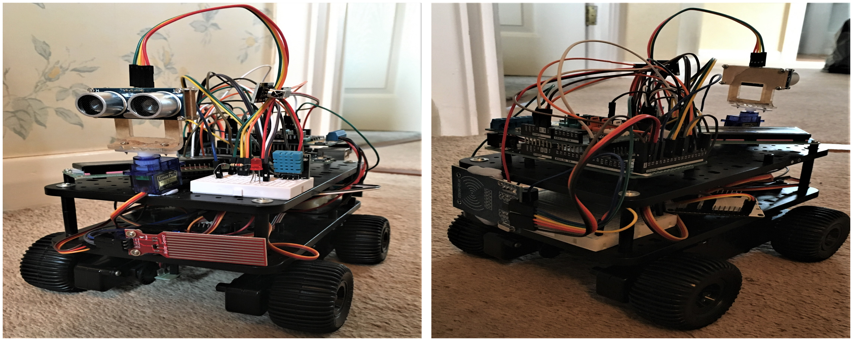
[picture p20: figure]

Figure 1: Left: Image of Buggy from the front left corner.

Figure 2: Right: Image of Buggy from rear right corner.

Below are two images of the main schematic of the buggy and a general communications diagram.

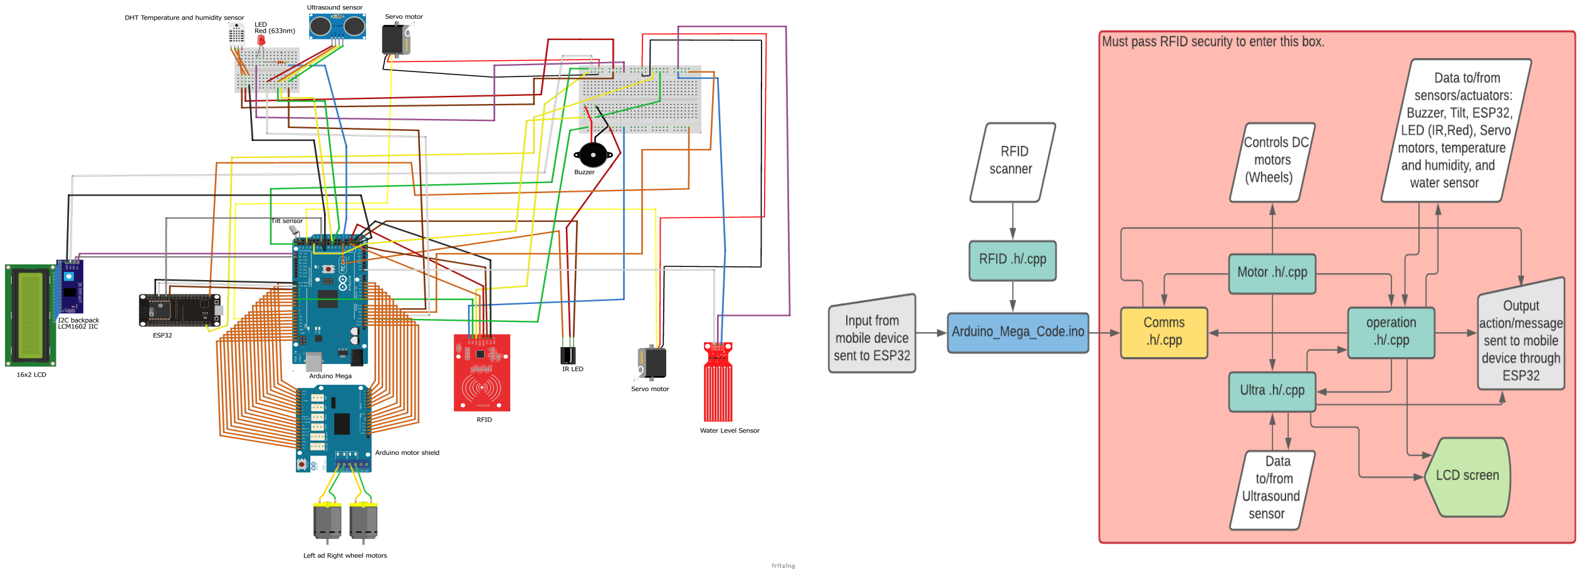
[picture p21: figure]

Figure 3: Left: Schematic of Buggy.

Figure 4: Right: Communication diagram of the Buggy

The software for the Arduino has been set up into header (.h) files and source code (.cpp) files where they are then called in the main code. There are many benefits to this such as the code is organised and tidy allowing future and current developers to debug with ease, addition of any new code can be easily integrated into the system and the code can be easily maintained.

Figure 5: Tabs for Arduino mega main code.

In Figure 4 you can see how the system communicates between source files. The main system that operates the buggy can not be accessed without first passing the RFID security tag challenge. Further development to encrypt data that is sent between the mobile device and ESP32 needs to be done, a attempt to create a rotation 13 encryption has been attempted but needs to be placed correctly within the architecture of the system.

## 3 Implementation

The software for the ESP32 comprised of individual sketch files which correspond to the use of WiFi or Bluetooth and for both due to the ESP32 being dual-core. Transmission control protocol (TCP) has been used when using WiFi instead of user diagram protocol (UDP) as is it more reliable, has Flow control so will not overwhelm receiver and has congestion control. A ’handshake’ is used to initiate communication and then multiple packets are sent. TCP may not be as fast as UDP but due to the project objectives, reliability is preferred. This being said TCP is slower by a very small margin so is not a large hindrance on the usability of the system.
A distributed system is a system which coordinates is actions by communicating between components via passing messages. The example for this project are listed and explained below.
- Mobile device-ESP32-Arduino maga: The mobile device communicated to the ESP32 through WiFi (TCP) or Bluetooth, the message that is received by the ESP32 in then passed onto the Arduino mega by universal asynchronous receiver/transmitter (UART). UART is not a communication protocol but is rather a physical circuit where serial data is transmitted and received. This emphasises the reliability factor as no data will be lost over the wired connection. When the Arduino receives a message/command the source code will then action this. If feedback is to then be sent back to the Mobile device it will do so in reverse process, the data will be sent to the ESP32 via UART and then be sent to the mobile device by WiFi/Bluetooth.
- IR signal-Arduino: The IR LED input signal was initially received in the mini-bread board but this cause problems while testing due to high volumes of noise, it was therefore moved directly onto the Arduino mega. This therefore means that the IR remote can by used at the same time as the mobile device. The LCD used the I2C bus to print messages on the screen when temperature, humidity and water sensor readings are requested.
- PC-Arduino: The PC is connected directly to the Arduino mega and is controlled using the serial monitor. It is very useful for conducting quick simple tests, if new code is added to the software for example.

- ESP32 disconnection feature: When the ESP32 disconnects from the WiFi router or Bluetooth then a signal will be sent to the Arduino mega. When this signal is recieved the buggy will stop, the LCD screen will be cleared and a red LED will light up to alert the user.

The interactivity between the buggy and the user (besides the obvious mobile device (WiFi/Bluetooth), PC communication and IR remote) consist of the following lower levels of interactiveness:

- RFID scanner- This provides security as the RFID tag/card must be presented before any use of the buggy can take place.
- Tilt sensor- This sends a message to the mobile device/PC aswell as sounding an alarm to communicate to the user that the buggy has tipped over due to complex/uneven terrain.
- Disconnection LED- The red LED on the front of the buggy lights up when the WiFi/Bluetooth connection drops.
- Ultrasound sensor- This interacts with its surroundings to gain distance information. This information can then be actioned on accordingly, for example while in an autonomous mode distance information will be used to make decisions and avoid obstacles.

These may seem like simple solutions but they are effective and prove effective during testing. They also provide a level of security to the buggy, for example if a new RFID tag is to be added it can only be done so by adding it to the source code.
when communications have been received from the mobile device by the ESP32 the ESP32 will receive this message and send it to the Arduino via UART as mentioned above. Any messages sent from the Arduino are communicated back in the same way.

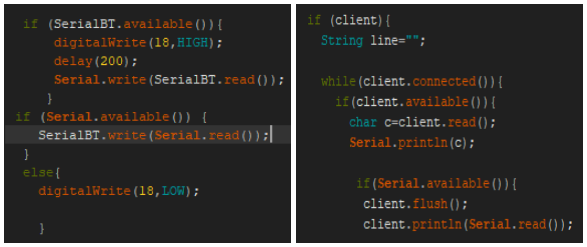
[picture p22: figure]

Figure 6: Left: ESP32 Bluetooth main loop code.

Figure 7: Right: ESP32 standard Wifi main loop code.

Blynk is a library that when connected to its app on any mobile device provides a very aesthetic design for the user, it is also very customizable for varying project requirements. The way it has been used in my case is of a similar procedure but is not as straightforward as the Bluetooth or standard WiFi set up. As you can see below, two functions are created with ’BLYNK_WRITE’ being a Blynk library that reads commands from the mobile device and sends them to the Arduino and ’SerialInput’ being the function which sends messages from the Arduino to the mobile device.

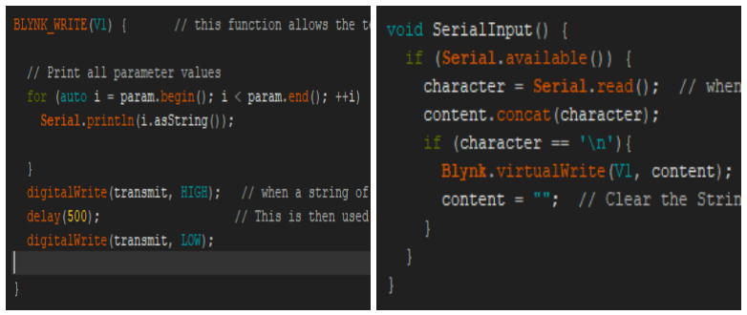
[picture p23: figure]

Figure 8: Left: ESP32 Blynk read from the mobile device and send messages to the Arduino Mega.

Figure 9: Right: ESP32 Blynk read meaasges from arduino and send to mobile device

The ESP32 is a Dual core micro-controller and in theory can be used for a combined Bluetooth and WiFi mode. As you can see from the figure below this was attempted and does work, however there is one issue issues. Because the procedure for sending messages back to the mobile devices are virtually the same for WiFi and Bluetooth the ESP32 has no distinction between which device it has received a command from and therefore which device to send messages back to.

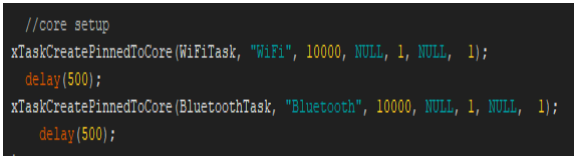
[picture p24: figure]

Figure 10: Setup for ESP32 dual core WiFi and Bluetooth.

Looking at the figure below you can see the main loop for the Arduino mega. The commands here are reading the serial monitor when the buggy is connected to the PC as well as the IR remote control reader and the ESP32 reader (this reads messages from the mobile device). Other commands that monitor the tilt sensor and the Wifi/Bluetooth connection are at the bottom of Figure 6.


Figure 11: Left: Arduino mega main loop

Figure 12: Right: Read incoming message

When a command is received from the mobile device it will enter a switch loop, here is where commands are executed. each command corresponds to a function which exist in other source code files.

## 4 Testing

The variety of testing methods used from start to finish have varied from unit and integration testing to acceptance and regression testing. The unit testing has taken place when a new operation/function has been added to the source code and is performed by myself for verification. The integration tests have then been performed by others to make sure that the new function works within the rest of the system and performs how it is expected to perform (acceptance testing). As the project has developed regression testing has been used to verify that any changes have not affected the prior system.
One of the first problems discovered was with the ultrasound sensor (USS), in complex environments the USS would not recognise the correct distance and the buggy would therefore crash. Complex environments such as chair legs and/or approaching a wall at a 45◦ angle. The reason for the USS difficulty in getting the correct distances is due to its transmitter-receiver setup, if either one is blocked then the correct distance cannot be obtained and the buggy crashes. For this reason, to reduce any damage to the hardware a tilt sensor was added. This feature when triggered will stop any movement of the buggy and will send a warning signal to the mobile device terminal.
///insert pic of unstable buggy message aswell as a chair leg infront of the ultrasound sensor with a distance reeding.
When the decision to add a IR remote which is able to control the buggy was made, initially there were issues. Noise from ambient light, other IR sources and even electrical signals within the breadboard caused overflow issues. Any command received from the IR remote would not be read and processed.
///add IR overflow screenshot
What I found was happening is that any electrical signal to or from the ultrasound sensor was being spread throughout the pins ports in the breadboard (This is due to it being a small cheap breadboard) and this interfered with the IR LED electrical signal. To over come this the signal pin for the IR LED was relocated to the main Arduino mega board, This reduced the noise considerably.
Of course loss of communication is a important problem. To combat this the ESP32 monitors WiFi/Bluetooth connection and if any connection is lost the ESP32 sends a signal to the Arduino Mega. This signal will stop the buggy and turn the front red LED light on. No message is sent to the mobile device as there is no connection so it would be pointless. When the connection is lost the LCD is also cleared. The ESP32 will attempt to restart the setup instructions to regain connection.
//// add photos os bluetooth disconnect with led lit up
Some basic tests on the accuracy of the ultrasound, temperature, humidity and water sensor were also conducted. When testing the accuracy of the ultrasound sensor a ruler was placed at the base of the sensor and a book was moved closer in intervals of 5cm starting from 120cm. The recorded result was then noted and compared against the actual result.
///Add photo of ultrasound setup and results.
When It came to testing the temperature, ///////
The water sensor was slightly different when it came to testing. The software is setup to provide a ranged output for the sensor reading (Empty, low, medium and High). These ranges can be calibrated in the source code, but I still tested the sensor to see how the difference in water levels affected the output. The sensor was split up into intervals and water is applied in cumulative segments. The output is then recorded, the output can be recalibrated depending on how the user wants it to be set up.
/// do water sensor test.

## 5 Evaluation

//// pros and cons of WIFI and bluetooth. //// limitations to each distributive method.
As you can see below when a command is sent from the Bluetooth terminal any messages responding to this command come back through the WiFi terminal and visa versa.


Figure 13: From Left to Right: Bluetooth terminal giving commands. WiFi terminal receiving messages. WiFi terminal sending commands. Bluetooth terminal receiving messages.

## 6 Code quality/remarks

////this may get cut if needed as in more an non written task ////discuss multi and single core methods in a ReadMe file!!!
///Layers- layered system to allow for easy maintenance, ease of updating/developing the system. ADD A DIAGRAM OF THE LAYERS HERE.

## 7 Demonstration

////film the video and then refer to it for the following subsections

### 7.1 Distribution

///Define what a distributed system is

### 7.2 Interactive

///Define what an interactive system is

### 7.3 Performance

## 8 Conclusion

## 9 Reference Library and appendices

### 9.1 Github account

Click here for Github hyper link (https://github.com/james8268/Buggy)
or copy and paste the URL into your web browser. https://github.com/james8268/Buggy

## List of Figures

1 | Left: Image of Buggy from the front left corner | | 1
2 | Right: Image of Buggy from rear right corner | | 1
3 | Left: Schematic of Buggy | | 2
4 | Right: Communication diagram of the Buggy | | 2
5 | Tabs for Arduino mega main code | | 2
6 | Left: ESP32 Bluetooth main loop code | | 3
7 | Right: ESP32 standard Wifi main loop code | | 3
8 | Left: ESP32 Blynk read from the mobile device and send messages to the Arduino Mega | | 4
9 | Right: ESP32 Blynk read meaasges from arduino and send to mobile device | | 4
10 | Setup for ESP32 dual core WiFi and Bluetooth | | 4
11 | Left: Arduino mega main loop | | 4

12 | Right: Read incoming message | | 4
13 | From Left to Right: Bluetooth terminal giving commands. WiFi terminal receiving messages.
| WiFi terminal sending commands. Bluetooth terminal receiving messages | | 6

### 9.2 Third party libraries

arduino.h, LiquidCrystal_I2C.h, IRremote.h, Wire.h, dht.h, SPI.h, MFRC522.h, WiFi.h, WiFiClient.h, BlynkSimpleEsp32.h, Servo.h and BluetoothSerial.h

### 9.3 Test Comments

Test 1
Getting to grips with the Bluetooth, 28/10/2020: The device worked exactly how it should every command button worked as it should. The controls were very easy to understand and get to grips with which means I could use the buggy how I wanted with no issues. Only thing I would like to add is that the left and right turns be a little less aggressive. So instead of a 90 degree turn maybe a 45 instead. Also I would like the distance of the sensor to be displayed on the mobile device as well as the LCD screen on the buggy so I dont have to be stood directly over the buggy to know this information, as I think this would make it more user friendly. Other than that, it was flawless.
Test 2
This test is like the last with a few minor changes. This time around the buggy is in a combined remote Bluetooth and autonomous mode. The autonomous element will allow the buggy to roam freely while avoiding obstacles.
Acting on the previous test a feature of being able to see the reading of the ultrasound sensor has now been added and can be viewed in the mobile device terminal as well as the turns being less harsh.
Test 2.1, using the combined autonomous and Bluetooth mode, 04/11/2020: self-roaming was effective, the buggy avoided obstacles well, although had trouble once it was under a certain distance from complex obstacles. commands were easy to pick up and the buggy was easy to manoeuvre, although lag time could be reduced, or possibly a cut off after x number of commands. possibly introduce a short cut to speed one and/or options for varying stop times, so that when flustered a driver can take time to re-think.
Test 2.2, test is the same as previous (code remains the same as the last test), 05/11/2020: the buggy avoided the obstacles well however due to lag it made it difficult to manoeuvre, also would be much easier and efficient for the driver if there was a cut off command so that the user can re-access the situation and move from there.
Test 3
The buggy now can roam around autonomously while avoiding obstacles and this can then be stopped and be used remotely again. Its easy to switch between the two, using the mobile device terminal the ”roam” hotkey enters the buggy into an autonomous mode(which can be seen when the android device is tilted on a landscape view and the screen will show more potential hotkeys). when any button/command is used in the terminal the buggy will then exit the autonomous mode and reverts to a remote mode.
Test 3, testing combined autonomous and remote modes, 07/11/2020: I enjoyed the new features on the handset. The fact that the buggy now had a roam feature was very interesting. The fact it could now make decisions on what was in front of it and change the course on which it was travelling due to an object being in its way was fascinating. A cool feature would be if it could decide which way it wanted to turn. For instance, left or right depending on the amount of space it has either side, this depends on the amount ultrasound sensors it has available. All the other buttons worked well and did what I wanted when I asked it to.
Test 4
A tilt sensor and servo motor have now been added, the use of WIFI connection is also up and running. Security measures have been added so if WIFI or Bluetooth connection is lost it will stop the buggy and turn on the front red LED. The servo motor allows the buggy to look left and right and then decide on which direction to move. The tilt sensor will monitor the buggy and if it capsizes or is flipped over it will stop the buggy and turn on a buzzer as well as notifying the user if in remote mode.
tests to be completed:
- turning system for servo ultrasound sensor, just to check its working right.
- tilt sensor while in autonomous mode while moving.
- temp and humidity sensor and water sensor while moving and stationary.
- disconnect functions via Bluetooth, by trying to connect another device (already known that two devices
| cant connect over Bluetooth).

- disconnect from WiFi, turn off router.
- test overall usability.

Test 4, 23/11/2020, testing the new obstacle avoidance system, tilt sensor and the temp, humidity and water sensor (all in Bluetooth mode): I found the new obstacle avoidance system was very good the Buggy made very accurate adjustments when it came to an obstruction. the fact it was able to stop look around and decide for itself which way to go was very impressive. the tilt sensor that has been integrated into the buggy was a very impressive feature. especially since you had the use of this both in autonomous mode and just when controlling the buggy, yourself. also having the bonus of a water, temp and humidity sensor on it was very good. being able to see those readings was a nice feature to have the use of. I also found the use of the IR remote to be far more simplistic and easier to use than the Bluetooth device I much preferred it. there was a few points I feel could do with some improvement. for instance, when you are on the move and then ask the buggy to perform a water reading it stops does this command but then waits for another new instructions. I would like it to instantly carry on with the previous command once the reading has been carried out with no need to give it further instruction from either the Bluetooth device or IR remote. other than that, the buggy was very good. Test 5
A RFID security tag has been added for security.
Test 5, first time using WIFI set up and looking at disconnection issues. To then compare the WIFI and Bluetooth usability, 11/12/20:
Using BLYNK: was detailed and easy to use. Very easy to read the screen. All commands worked straight away. Liked the safety feature as well the fact you had to use a key fob to be able to use the buggy. Also, the fact it tells you on the buggy with a red led that it is disconnected from the internet and you no longer have control of the buggy.
Standard WIFI: wasnt as easy to use. Didnt like the fact every time you placed a command the keyboard went away so you had to click on the box again to load a command. When I asked for a temp reading it wasnt displayed on the WIFI app. Just gave me a random number. Also, when disconnected from the internet the red led light didnt show on the buggy to indicate it was inoperable, however it did show on the WIFI app that it had been disconnected from the network.
Comparison to Bluetooth: WIFI was good but the Bluetooth was far better in my opinion as I can used the buggy anywhere at any time I like with ease. Whereas with the WIFI you must have that connected to be able to use the buggy. Also, the Bluetooth has the hot keys which made the whole experience of using the buggy more user friendly and easier.

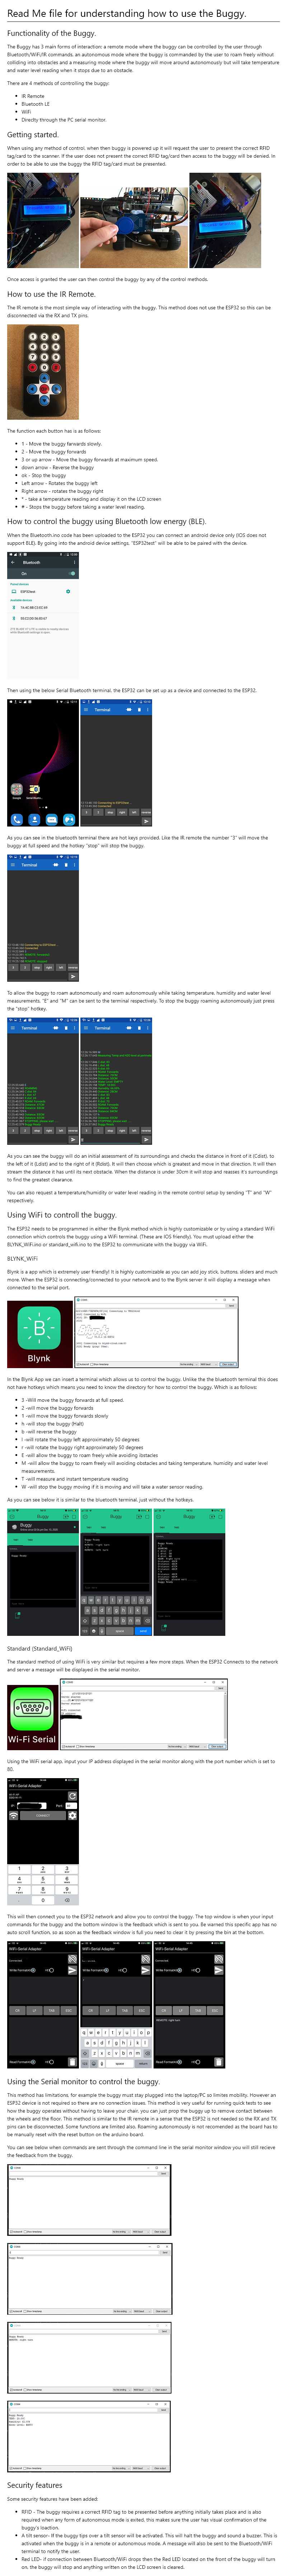
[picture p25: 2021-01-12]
README.png

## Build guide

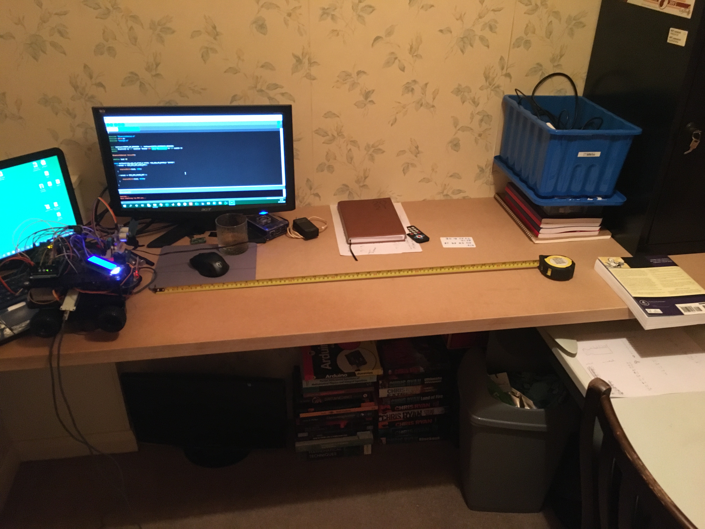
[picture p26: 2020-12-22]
Documentation/USS_setup.JPG

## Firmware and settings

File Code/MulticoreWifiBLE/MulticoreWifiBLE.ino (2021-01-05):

#include "BluetoothSerial.h"
#include <Wire.h> 


#define BLYNK_PRINT Serial    //defines the mobile deivce as a serial terminal

#include <WiFi.h>
#include <WiFiClient.h>         //include the needed header files, including the Blynk library.
#include <BlynkSimpleEsp32.h>



#if !defined(CONFIG_BT_ENABLED) || !defined(CONFIG_BLUEDROID_ENABLED)         //enable Bluetooth.
#error Bluetooth is not enabled! Please run `make menuconfig` to and enable it
#endif


String content = "";   
char character;

char auth[]= "jVAGDLSq2_VTo2K_l74wrM509taT5Bty";  // author token allows the Blynk app to to link with this project.

char ssid[]="VM9234142";    //internet SSID and password. 
char pass[]= "hgyb9tqPdhfw";

WidgetTerminal terminal(V1);   // declares the terminal is linked to the virtual pin 1.

BluetoothSerial SerialBT;

#define transmit 18   // pin 18 sends a signal to the Arduino when any transmition is occuring.
#define lost 19       // pin 19 sends a signal to the arduino if the WiFi connection is lost, this allows the buggy to stop moving. 


BLYNK_WRITE(V1) {       // this function allows the terminal on the mobile device to communicate to the ESP32 Serial. 

  // Print all parameter values
  for (auto i = param.begin(); i < param.end(); ++i) { // this for loop sets the condtions needed to read the messages as a string from the terminal  
    Serial.println(i.asString());
   
  }
  digitalWrite(transmit, HIGH);   // when a string of communication recieved by the esp32 it will cause the transmit pin to output as high for half a second.
  delay(500);                    // This is then used by the arduino mega in the operation.roam() 
  digitalWrite(transmit, LOW);


}


void SerialInput() {
  if (Serial.available()) {  
    character = Serial.read();  // when a serial is available, read what has been printed
    content.concat(character); 
    if (character == '\n'){  
      Blynk.virtualWrite(V1, content);  // the characters have been gathered and are then sent to the mobile devices terminal 
      content = "";  // Clear the String to be able to reciver a new message without repeating what was said previously. 
    }
  }
}



void setup(){
  //Bluetooth setup 
  Serial.begin(9600); 
  SerialBT.begin("ESP32test"); //Bluetooth device name 
  pinMode(transmit,OUTPUT);
  pinMode(lost, OUTPUT);

//WiFi setup
Blynk.begin(auth, ssid, pass);     // this is where the esp32 connects to the WiFi and Blynk servers. 
terminal.clear();                  // clear the mobile terminal
Blynk.virtualWrite(V1, "Welcome MR Ravenhill, I'm ready to recieve commands");     // welcome message printed in the mobile terminal.


  //core setup
xTaskCreatePinnedToCore(WiFiTask, "WiFi", 10000, NULL, 1, NULL,  1);   //create a task on one CPU that uses WiFi
  delay(500);  
xTaskCreatePinnedToCore(BluetoothTask, "Bluetooth", 10000, NULL, 1, NULL,  1);   //create another task on the remaining CPU to handle Bluetooth communication.
    delay(500); 
}


void WiFiTask( void * pvParameters ){      // This is the WiFi communication loop 
for(;;){

 Blynk.run();    //this runs all the Blynk functions 
SerialInput();

 if(WiFi.status() != WL_CONNECTED){digitalWrite(lost, HIGH);  //This monitors the WiFi connection. 
 setup();}
 else{digitalWrite(lost, LOW);}
    
  }
}

void callback(esp_spp_cb_event_t event, esp_spp_cb_param_t *param){      //This callback is monitoring bluetooth connection.
  if(event == ESP_SPP_SRV_OPEN_EVT){
   
     digitalWrite(lost, LOW);
  }
 
  if(event == ESP_SPP_CLOSE_EVT ){
    
      digitalWrite(lost, HIGH);
  }
  
}

void BluetoothTask( void * pvParameters ){   //This loop is responsible for Bluetooth communication 
  for(;;){
 if (SerialBT.available()){
      digitalWrite(transmit,HIGH);
      delay(200);
      Serial.write(SerialBT.read());
     }
 
 if (Serial.available()) {
    SerialBT.write(Serial.read());
  } 
  
  else{ 
    digitalWrite(transmit,LOW);

    }

  SerialBT.register_callback(callback);   //This checks the Bluetooth connection using the callback function. 
  }
}


void loop() {
}

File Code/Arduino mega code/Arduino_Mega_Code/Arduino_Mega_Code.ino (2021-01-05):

// This is the main code, It is uploaded to the Arduino Mega. It contains the setup functions for specific libraries. 

// used baud rates: 9600(ESP32), 4800 (Ultrasound)

#include "Arduino.h"
#include "Motor.h"
#include "Ultra.h"
#include "Comms.h"   // Include all headers needed for the buggy's opertion
#include "Wire.h"
#include "operation.h"
#include "RFID.h"


void setup() {

Motor.SETUP();     
Ultra.SETUP();       // all the header files are setup. 
Comms.SETUP();
operation.SETUP();
RFID.RFIDsetup();
}

void loop() {



if(RFID.RFID_challenge()==true){    //Check if the RFID tag has been scanned, if so then it will be true and operation can commence
  Serial.println("Buggy ready for commands");
  for(;;){            
    
if(Serial.available()){   //This allows the Buggy to be controlled via the serial monitor when connected to a PC.  
 Comms.read_message();
  }

operation.IRread(); //read the IR sensor if a order has been sent from the controller
Comms.read_message();   // this reads recieved commands and performs the output function. 
operation.level();  // this function will stop the buggy if the tilt sensor is triggered, a buzzer and warning message will alert the user. 
operation.noINT();  // this function monitors the connection between the ESP32 and wifi/bluetooth connection. If connection is lost the front red LED will light up. 
  }
}        

}


  

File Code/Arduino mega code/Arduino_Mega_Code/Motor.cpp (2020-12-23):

#include "arduino.h"
#include "Motor.h"          //include our header file


const uint8_t dirA = 12;    //set up the pins which correspond to direction, break and PWM of our two DC motors.
const uint8_t dirB = 13;
const uint8_t brA = 9;
const uint8_t brB = 8;
const uint8_t pwmA = 3;
const uint8_t pwmB = 11;


Motorclass::Motorclass() {} // setup motor class

void Motorclass::SETUP() { //setup function

    pinMode(dirA, OUTPUT);  //all direction and break pins are set to OUTPUT. 
    pinMode(dirB, OUTPUT);
    pinMode(brA, OUTPUT);
    pinMode(brB, OUTPUT);

}

void Motorclass::forwards1() {  //function to move buggy forward at a low speed 

    digitalWrite(dirA, LOW);
    analogWrite(pwmA, 100);         //both motors will move in the same direction, due to them being in a opposing setup. One will be set to HIGH and the other LOW
                                    // this will move both motors in a forwards direction in our global coordinates 
    digitalWrite(brA, LOW);

    digitalWrite(dirB, HIGH);
    analogWrite(pwmB, 100);        //the power output sits at 100/255.
    digitalWrite(brB, LOW);

}


void Motorclass::forwards2() {  //function to move buggy forward at a medium speed 


     digitalWrite(dirA, LOW);
    analogWrite(pwmA, 175);
    digitalWrite(brA, LOW);

    digitalWrite(dirB, HIGH);
    analogWrite(pwmB, 175);        //the power output sits at 175/255
    digitalWrite(brB, LOW);

}

void Motorclass::forwards3() {  //function to move buggy forward at full speed

     digitalWrite(dirA, LOW);
    analogWrite(pwmA, 255);
    digitalWrite(brA, LOW);

    digitalWrite(dirB, HIGH);
    analogWrite(pwmB, 255);    //the power sits at its maximum Pulse-width modulation (PWM) 255/255.
    digitalWrite(brB, LOW);  

}
 



void Motorclass::backwards() {  // function to move buggy backwards at PWM 200/255

    digitalWrite(dirA, HIGH);
    digitalWrite(brA, LOW);     
    analogWrite(pwmA, 200);

    digitalWrite(dirB, LOW);
    digitalWrite(brB, LOW);
    analogWrite(pwmB, 200);
}

void Motorclass::halt() {  // function to stop buggy from moving by applying both breaks
    digitalWrite(brA, HIGH);

    digitalWrite(brB, HIGH);
}

void Motorclass::right90() {  // function to rotate buggy to right by setting both motors clockwise at PWM 200/255

    digitalWrite(dirA, HIGH); 
    analogWrite(pwmA, 200);
    digitalWrite(brA, LOW);
   

    digitalWrite(dirB, HIGH);
    digitalWrite(brB, LOW);
    analogWrite(pwmB, 200);

    delay(500);

    halt();
}


void Motorclass::left90() {  //function to rotate buggy to the left by setting both motors anticlockwise at PWM 200/255

    digitalWrite(dirA, LOW);
     analogWrite(pwmA, 200);
    digitalWrite(brA, LOW);
    

    digitalWrite(dirB, LOW);
    digitalWrite(brB, LOW);
    analogWrite(pwmB, 200);

    delay(500);

    halt();

};


Motorclass Motor = Motorclass();

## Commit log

2020-10-27 initial upload
    contains initial motor,bluetooth,ultrasound code with most previous update being an addition if a geared speed system
2020-10-27 interrupt added
    interrupt added via output from the esp32 to a PCINT pin on the mega board. main code updated accordingly. issue with interrupt, its connecting but not running the ISR.
    [Bluetooth.ino, Ultra.cpp, master.ino]
2020-10-28 tinkering
    interrupt
2020-10-30 Distance in bluetooth terminal
    Ultrasound distance displayed in the bluetooth terminal completed, no bugs found
    [Bluetooth.ino, Ultra.cpp, master.ino]
2020-11-02 interrupt fixed
    interrupt has been fixed but need some fine tuning e.g. bluetooth terminal displays distance when interrupt used not every 0.5 secs. also put code into a class.
    next steps are to create a overall stop i.e. pause function and then a continue function
    [Bluetooth.cpp, Bluetooth.ino, Motor.cpp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]
2020-11-05 fixing dual remote and roam modes
    interrupt may or may not bee needed.
    AIM: to create a function which allows the user to shift between a remote and roam mode. doesnt work yet, clode but lots of bugs.
    [Bluetooth.cpp, Motor.cpp, master.ino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]
2020-11-06 combined remote and roaming modes fixed!
    no bugs found, this is working well. will be the next user test (test 4).
    [Bluetooth.cpp, Motor.cpp, master.ino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]
2020-11-06 buggy schematic
    esp32 needs editing
    [buggy project.fzz]
2020-11-07 schematic for buggy update
    ESP32 is now correct
    [buggy project.fzz]
2020-11-07 combitation remote auto bug fixed
    fixed a bug found in the operations class where roam would not restart, this has been fixed ad is working as it should.
    [Bluetooth.cpp, master.ino, operation.cpp]
2020-11-10 using the ESP in WiFi mode
    able to communicate from the serial monitor to the phone monitor but not the other way around yet as this need researching and fixing.
    [ESP32_WiFi.ino]
2020-11-11 communication complete
    communication complete, communication between the terminal and serial are working, next stage is to develop a security measure when it disconnects
2020-11-14 Servo observer added
    mount has been ordered for the servo as bluetac is not working very well. yet to be tested but seems to be working well.
    [Motor.cpp, Ultra.cpp, master.ino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]
2020-11-14 added a tilt sensor
    needs fixing and placing where it will work
    [Motor.cpp, master.ino, operation.cpp]
2020-11-16 tilt sensor fixed and working
    tilt sensor now works in the remote and roaming mode.
    now working in security measure when connection is lost
    [Bluetooth.cpp, master.ino, operation.cpp]
2020-11-16 Esp32 lost connection created
    safety measure created and LED on buggy indicates if connection is lost. These need to be tested but should sofice.
    Bluetooth sketch needs to have a connection lost safety measure.
    [Bluetooth.cpp, ESP32_WiFi.ino, operation.cpp]
2020-11-18 IR Remote added
    This work ok in remote mode, would avoid using in roaming mode due to amount of noise and of course due to distance between user and buggy it would be impracticle. need to add a connection lost to bluetooth function, similar to the wifi one..
    [Bluetooth.cpp, Bluetooth.ino, ESP32_WiFi.ino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]
2020-11-21 Temp, Humid and water sensor added
    Sensors added. observing all so sorted, will now check the front not just left and right.
    Next steps is to sort out the IR senor on ESP as is either broken or refusing to work. Also to work on feedback given on section 4(Bulletpoint tests) which are to be conducted tomorrow hopefully.
    [Bluetooth.cpp, Bluetooth.ino, Ultra.cpp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]
2020-11-23 updated schematic
    [buggy project.fzz]
2020-11-25 multicore wifi and bluetooth created
    the use od dual core works well but are a lot of issues that need fixing/testing.
    Documentation has been starter.
    Connection lost need to be improved! either needs to be set as an interrupt, if this is to complex for the interrupt set up then just reset the board. Would be nice to have a function where nothing happens until the board and the device is paired and not just the board being ready, set all pins OFF. if need be.
    [buggy project.fzz]
2020-11-30 Wifi client
    addition/in the process of creating a wifi client to control the buggy
    [Bluetooth.cpp]
2020-12-01 wifi ip and wifi server reader
    wifi ip- uses esp32 as a station and access point where a client has been created and a 'menu' is used to control the buggy. This has to many issues to deal with however- there is no feeback from the buggy. It is not communication to the buggy clearly.
    Wifi server reader works well- it communicates to the buggy clearly using the IP address and port number. Feedback works but not well. this needs fixing.
    [wifi_server_reader.ino]
2020-12-04 connection issues sorted and new measure function added
    blynk is ok but the buggy reads the connecting data and actions it.
    [Bluetooth.cpp, Bluetooth.ino, ESP32_WiFi.ino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]
2020-12-11 test 6 complete
    [buggy project.fzz]
2020-12-16 issue with wifi strandard fixed
    [buggy project.fzz]
